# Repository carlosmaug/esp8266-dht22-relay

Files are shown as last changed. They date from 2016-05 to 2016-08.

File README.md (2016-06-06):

# ESP8266 model 1  DHT22 or DHT11 realy control

Turns on/off a relay based on reading of temperature and humidity of a DHT22 or DHT11 sensor. Optionally you can turn on/off relay manually using the web interface.

Web interface lets you connect to your wifi, configure defaut values, see DHT readings, turn on/off the relay, and other things.

In this version you will find:
- New Web interface, now responsive.
- New configuration web page added.
- New Relay control page.
- Configuration is kept after reset.
- Fallback to AP mode in case of loosing access to AP.
- Tons of code and circuit testing.
- Added circuit schema.
- All configuration is now placed in a single file.
- Added deug mode to reduce console vervosity.
- Compatibility with esp iot sdk v1.5.4 

Seccurity issues
- MANY.... 
- Wifi password is very easy to retrieve from the web interface.
- No support for ssl nor tls, or any other form of encription.
- No password support.
- It is still pending the use of snprintf.
- ETC..

# Configuration

There are a few parameters that can be changed:
 * include/config.h: Temperature and humidity boundaries to turn on relay, number of  minutes to keey relay on since it was manually turned on, sensor type (DHT11 or DHT22) and poll rate
 
# Building

Make sure the IoT SDK and toolchain are set up according to the instructions on the [ESP8266 wiki](https://github.com/esp8266/esp8266-wiki/wiki/Toolchain). The makefile in this project relies on some environment variables that need to be set. It should be enough to add these to your `.profile`:

	PATH="/opt/Espressif/crosstool-NG/builds/xtensa-lx106-elf/bin/:$PATH"
	export SDK_BASE="/opt/Espressif/ESP8266_SDK"
	export XTENSA_TOOLS_ROOT="/opt/Espressif/crosstool-NG/builds/xtensa-lx106-elf/bin/"
	export ESPTOOL="/opt/Espressif/esptool-py/esptool.py"

From the root of this repository, run `make`. This will build the two firmware images. 

# Screenshots

## Web interface

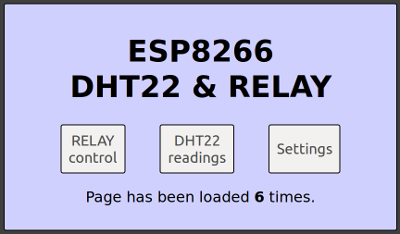
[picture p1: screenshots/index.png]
index

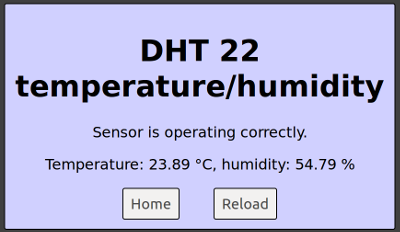
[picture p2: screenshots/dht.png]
dht

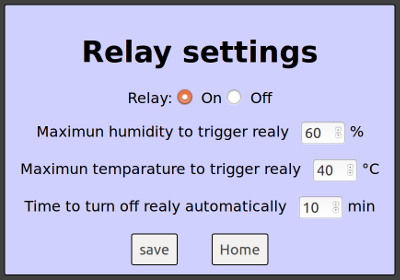
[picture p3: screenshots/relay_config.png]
Realy settings

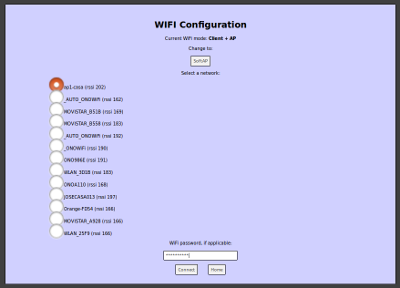
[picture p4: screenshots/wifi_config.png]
WIFI config


# Hardware

We have included all information and schemas inside the eagle directory. You can edit them using eagle software.

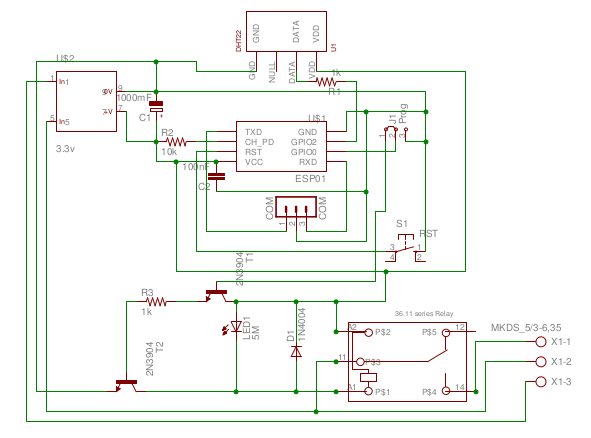
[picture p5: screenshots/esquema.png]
Schema


# Background

This application is based on [Mathew Hall](https://github.com/mathew-hall/esp8266-dht) software, which in turn is based on others, like [Martin's DHT22 webserver](http://harizanov.com/2014/11/esp8266-powered-web-server-led-control-dht22-temperaturehumidity-sensor-reading/) implementation, which uses [sprite_tm's ESP8266 httpd](http://www.esp8266.com/viewtopic.php?f=6&t=376).

# Licenses

Please refer to each file to see the licences.

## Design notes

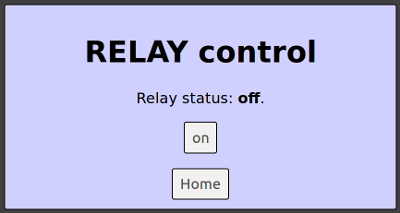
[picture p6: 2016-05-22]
screenshots/relay.png

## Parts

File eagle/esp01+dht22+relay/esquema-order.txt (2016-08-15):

Order list for /home/carlos/eagle/esp01+dht22+relay/esquema.sch
Exported from EAGLE with DesignLink

Quantity	Value	Package	Order code	Manufacturer	Manuf. Code	Availability	Price (from)	Description
1	1N4004	DO41-10	1836082	VISHAY	1N4004-E3/54	4252	0.0211	VISHAY - 1N4004-E3/54 - STANDARD DIODE, 1A, 400V, DO-204AL
1	5M	LED3MM	9477292	VISHAY	HVR3700001504JA100	25284	0.0587	VISHAY - HVR3700001504JA100 - RESISTENCIA, 1M5
2	1k	0204/5	9339051	MULTICOMP	MCF 0.25W 1K	238055	0.0055	MULTICOMP - MCF 0.25W 1K - RESISTENCIA, PELÍ CARBÓN, 1K, 0.25W, 5%
1	10k	0204/5	9339060	MULTICOMP	MCF 0.25W 10K	486540	0.0056	MULTICOMP - MCF 0.25W 10K - RESISTENCIA, PELÍ CARBÓN, 10K, 0.25W, 5%
1	2k	0204/5	9341480	MULTICOMP	MF25 2K	153426	0.0072	MULTICOMP - MF25 2K - RESISTENCIA, 2K, 0.25W, 1%
2	SWITCH-MOMENTARY-2SMD-12MM	TACTILE-SMD-12MM	1960936	OMRON ELECTRONIC COMPONENTS	B3F1002	27008	0.128	OMRON ELECTRONIC COMPONENTS - B3F1002 - SWITCH, FLAT, 6X6X4.3, 150GF
1	Power Line	03P	3041360	PHOENIX CONTACT	1725669	10876	0.706	PHOENIX CONTACT - 1725669 - BLOQUE TERMINAL, PCB, 2,54 MM, 3 VÍAS
1	COM	MA03-1	2313705	MOLEX	47053-1000	41677	0.0872	MOLEX - 47053-1000 - MACHO, 4 POSICIONES, 1FILA, 2,54 MM
2	2N3904	TO92	1574370	MULTICOMP	2N3904	112693	0.043	MULTICOMP - 2N3904 - TRANSISTOR, NPN, TO-92
1	ESP01	ESP01	unknown					
1	3.3v	1	1825772	MYRRA	47121	160	7.83	MYRRA - 47121 - FUENTE DE ALIMENTACIÓN, 3,3V, 2,5W
1	RELAYPTH	RELAY-G5Q	2311439	FINDER	36.11.9.012.4011	820	0.92	FINDER - 36.11.9.012.4011 - RELÉ, SPDT, 250VAC, 10A
1	DHT22	RHT03_DHT-22	unknown

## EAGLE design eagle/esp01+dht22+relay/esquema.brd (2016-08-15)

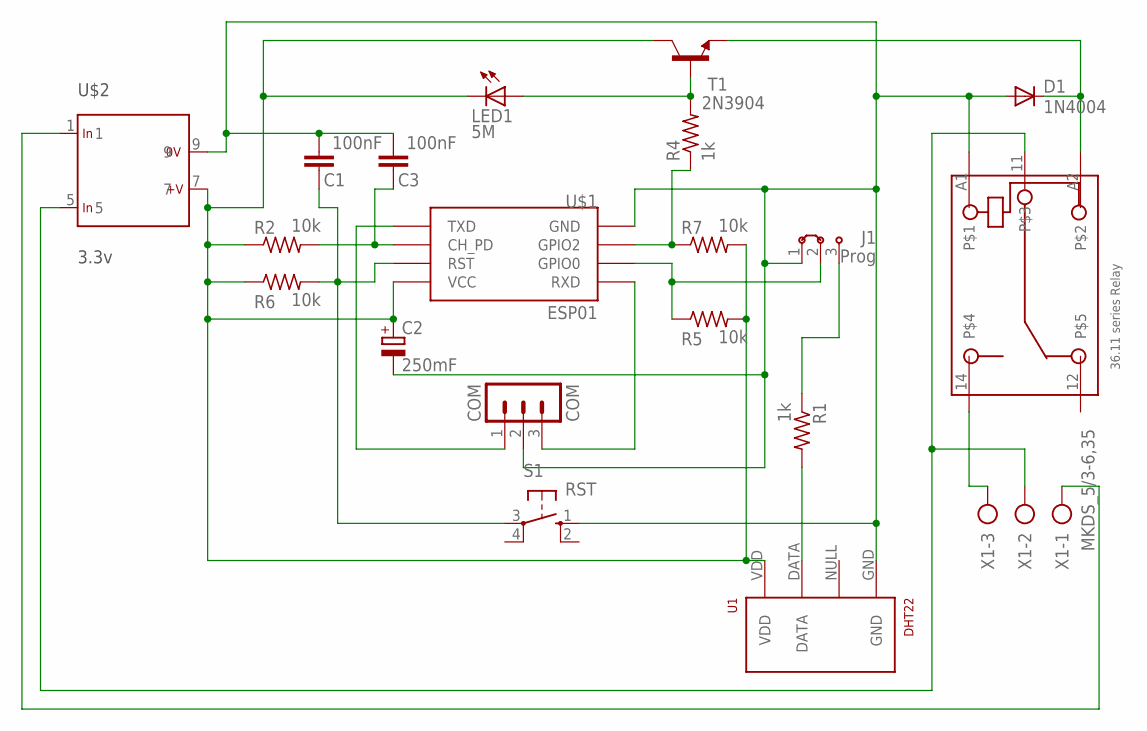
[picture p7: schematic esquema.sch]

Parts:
C1, C3: 100nF; CAP-PTH-SMALL-KIT
C2: 250mF; E2-5
COM: COM; MA03-1; MPN 47053-1000
D1: 1N4004; DO41-10; MPN 1N4004-E3/54
J1: Prog; 04C
K1: 36.11
LED1: 5M; LED3MM; MPN HVR3700001504JA100
R1: 1k; 0204/5; MPN MCF 0.25W 1K
R2, R5, R6, R7: 10k; 0204/5; MPN MCF 0.25W 10K
R4: 1k; 0204/5; MPN MCF 0.25W 10K
S1: RST; B3F-10XX
T1: 2N3904; TO92; MPN 2N3904
U1: DHT22; RHT03_DHT-22
U$1: ESP01
U$2: 3.3v; 1; MPN 47121
X1: MKDS_5/3-6,35; MKDS_5/3-635

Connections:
GPI02: R4.1, R7.1, U$1.GPIO2
GPIO0: J1.2, R5.1, U$1.GPIO0
unnamed: D1.C, K1.A2, T1.3 (E)
unnamed: C3.1, R2.2, U$1.CH_PD
unnamed: J1.3, R1.1
unnamed: K1.11, U$2.5, X1.2
unnamed: LED1.A, R4.2, T1.2 (B)
unnamed: R1.2, U1.DATA
unnamed: COM.1, U$1.TX (TXD)
unnamed: COM.3, U$1.RX (RXD)
unnamed: U$2.1, X1.1
unnamed: K1.14, X1.3
RST: C1.1, R6.2, S1.3, U$1.RST
V0: C1.2, C2.-, C3.2, COM.2, D1.A, J1.1, K1.A1, S1.1 (S), U1.GND, U$1.GND, U$2.9
V+: C2.+, LED1.K (C), R2.1, R5.2, R6.1, R7.2, T1.1 (C), U1.VDD, U$1.VCC, U$2.7

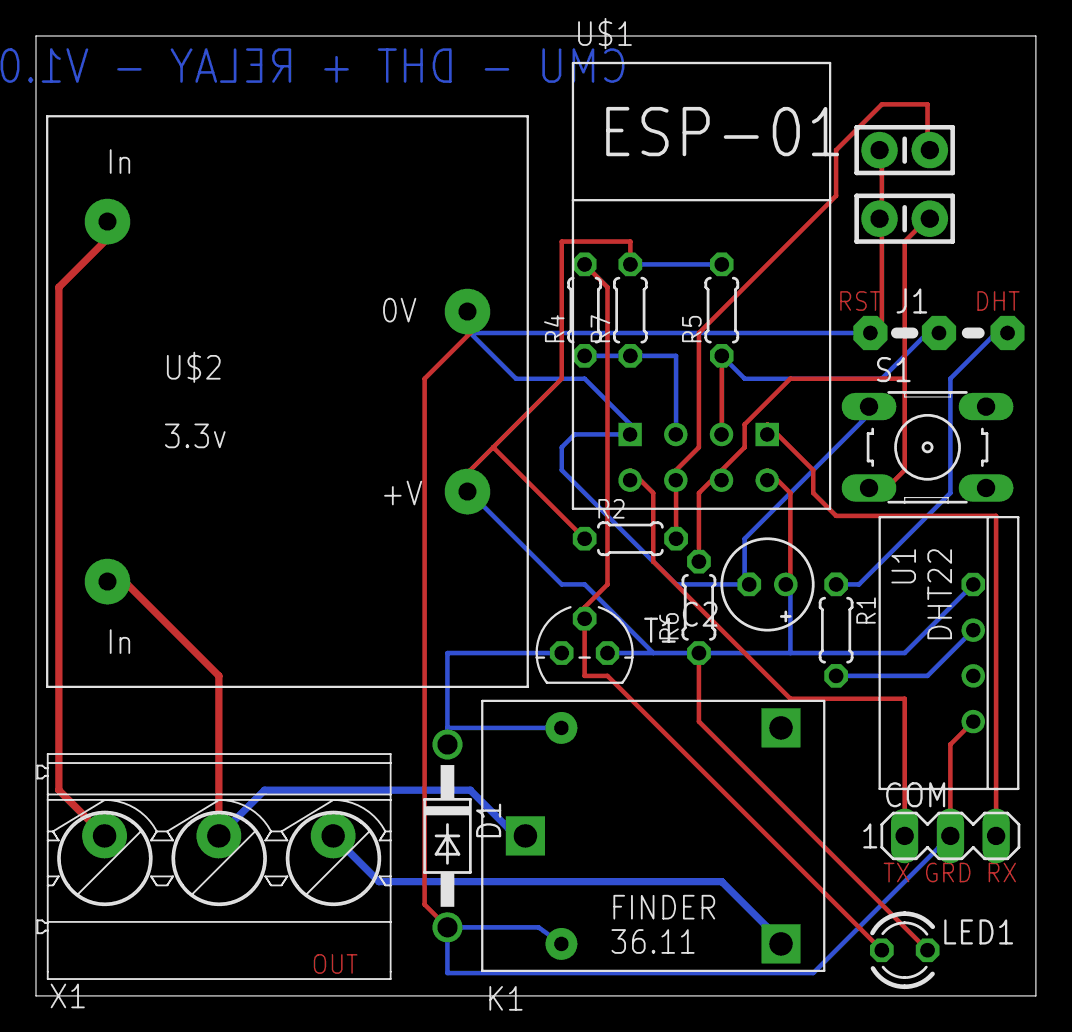
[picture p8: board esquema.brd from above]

Board: 2 copper layers, 55.5 x 53.3 mm, 20 parts (0 on the bottom side), 15 nets.

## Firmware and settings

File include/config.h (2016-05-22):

// Above this temp we turn on ralay
#define DEFAULT_TEMP 40
// Above this humidity we turn on ralay
#define DEFAULT_HUM  60
// If the relay is turned on manually, we turn it off after this number of minutes
#define DEFAULT_TIME 10
// 0 Relay operates normally, 1 relay does not turn on automatically
#define DEFAULT_OFF   0
// Valid values are: 'SENSOR_DHT22' or 'SENSOR_DHT11'
#define SENSORTYPE    SENSOR_DHT22
// Time between readings of sensor
#define POOLTIME  30000

struct config {
	short int checksum;
	short int hum;
	short int temp;
	short int time;
	short int off;
};


void config_init(void); 
int config_save(struct config save); 
struct config config_read(void);

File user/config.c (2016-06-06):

/****************************************************************************
 * Copyright (C) 2016 by Carlos Martin Ugalde and Ignacio Ripoll García     *
 *                                                                          *
 * This file is part of Box.                                                *
 *                                                                          *
 *   Box is free software: you can redistribute it and/or modify it         *
 *   under the terms of the GNU Lesser General Public License as published  *
 *   by the Free Software Foundation, either version 3 of the License, or   *
 *   (at your option) any later version.                                    *
 *                                                                          *
 *   Box is distributed in the hope that it will be useful,                 *
 *   but WITHOUT ANY WARRANTY; without even the implied warranty of         *
 *   MERCHANTABILITY or FITNESS FOR A PARTICULAR PURPOSE.  See the          *
 *   GNU Lesser General Public License for more details.                    *
 *                                                                          *
 *   You should have received a copy of the GNU Lesser General Public       *
 *   License along with Box.  If not, see <http://www.gnu.org/licenses/>.   *
 ****************************************************************************/

/**
 * @file config.c
 * @author Carlos Martin Ugalde and Ignacio Ripoll García
 * @date 15 May 2016
 * @brief File containing configuration save/recover functions.
 *
 * Ralay is turned on and off depending on DHT readins and the parameters set 
 */

#include <esp8266.h> 
#include <config.h> 

// https://github.com/esp8266/esp8266-wiki/wiki/Memory-Map
// Acording to this map we wave 4k free starting on 0x7B00
#define CONFIG_SECTOR 0x7B

// To write , you need the sector address. 
#define CONFIG_ADDRESS (SPI_FLASH_SEC_SIZE * CONFIG_SECTOR)

void _read(void);
int _write(struct config conf);
void _default_data(void); 

struct config confRead;

// Get saved config on startup
void config_init() {
	_read();
	os_printf("Initial config; Humidity %d, Temperature: %d, Off: %d\n", confRead.hum, confRead.temp, confRead.off);
}

// Save config and check if it is correctly stored.
int config_save(struct config save) {
	if (_write(save)) {
		return 1;
	}

	confRead = save;

	if (memcmp(&confRead, &save, sizeof(struct config)) != 0) {
		return 1;
	}

	return 0;
}

// Read config 
struct config config_read() {
	return confRead;
}

// Read stored config
void _read() {
	
	int sum1 = 0; 
	int sum2 = 0;
	short int i;
	unsigned char *vector;
	
	os_printf("Reading initial config\n");

	if (spi_flash_read(CONFIG_ADDRESS, (uint32*) &confRead, sizeof(struct config)) != SPI_FLASH_RESULT_OK) {
		os_printf("Error reading stored data from address: %x.\n", CONFIG_ADDRESS);
		_default_data();
	}

	vector = (unsigned char *) os_malloc(sizeof(confRead));
	os_memcpy(vector, &confRead, sizeof(confRead));

	for (i = 2; i < sizeof(confRead); i++) {
		sum1 = (sum1 + vector[i])%255;
		sum2 = (sum2 + sum1)%255;
	}

	os_free(vector);	

	os_printf("Checksum: %d\n",((sum2<<8)|sum1));
/*	
	if (((sum2<<8)|sum1) != confRead.checksum) {
		os_printf("Checksum error.\n");
		_default_data();
	}
*/
}

// Write config
int _write(struct config conf) {
	ETS_UART_INTR_DISABLE();

	if (spi_flash_erase_sector(CONFIG_SECTOR) != SPI_FLASH_RESULT_OK) {
		os_printf("Error erasing sector CONFIG_SECTOR.\n");
		ETS_UART_INTR_ENABLE();
		return 1;
	}

	if (spi_flash_write(CONFIG_ADDRESS, (uint32*) &conf, sizeof(struct config)) != SPI_FLASH_RESULT_OK) {
		os_printf("Error writing data to sector: %d\n", CONFIG_SECTOR);
		ETS_UART_INTR_ENABLE();
		return 1;
	}

	os_printf("Data saved correctly.\n");
	ETS_UART_INTR_ENABLE();
	return 0;
}

// Set default data 
void _default_data() {
	confRead.hum = DEFAULT_HUM;
	confRead.temp = DEFAULT_TEMP;
	confRead.time = DEFAULT_TIME;
	confRead.off = DEFAULT_OFF;

	if (config_save(confRead)) os_printf ("Error saving default data\n");
}

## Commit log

2016-05-22 Nada que comentar
2016-05-22 Cambio en el tamaño de las imágenes, las hacemos más pequeñas
2016-05-22 Ficheros necesarios para la correcta compilación del proyecto
2016-05-22 Necesario para poder imprimir a consola.
2016-06-06 Pasamos a depender de libesphttp
2016-06-06 Pasamos a depender de libesphttpd
2016-08-15 Eagle schemas
    [DRILEGEND.CFG, esquema.brd, esquema.sch]

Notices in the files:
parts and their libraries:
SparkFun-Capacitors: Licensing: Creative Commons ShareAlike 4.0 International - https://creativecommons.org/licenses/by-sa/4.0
